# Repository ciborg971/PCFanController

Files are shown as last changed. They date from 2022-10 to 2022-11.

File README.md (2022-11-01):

# PCFanController

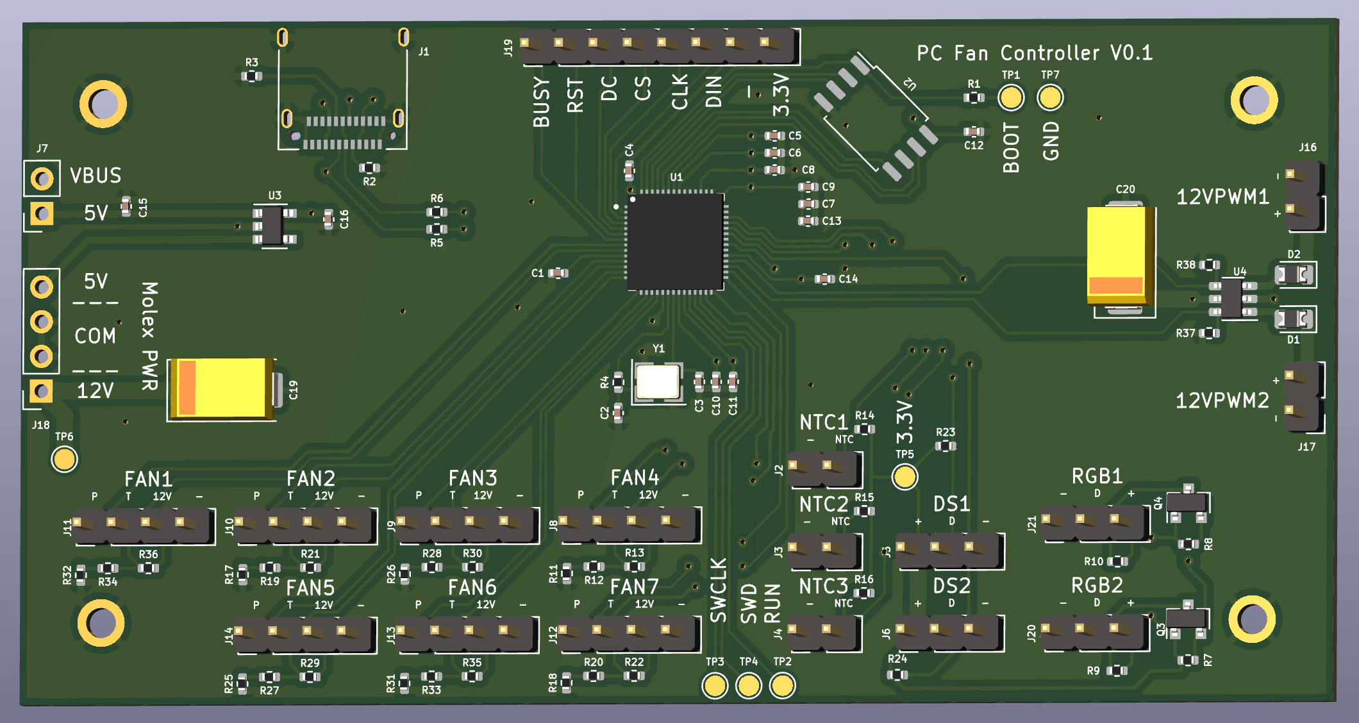
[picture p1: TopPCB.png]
PCB top view


A completly ~~overkill~~ sound and smart fan controller able to :
- use RP2040
- have USB-C
- 3x NTC 10K sensor (temperature sensor)
- 2x separated buses for DS18B20 (more temperature sensor)
- 2x separated WS2812 buses (RGB led)
- E-Ink display support
- 7x PWM fan support with tachymeter reading
- 2x 12 volt PWM output (Up to 20A per port)
- 2.5 inch hdd dimension (100 x 50 mm)
- M2 hole (between hole 85.25 x 38 mm)

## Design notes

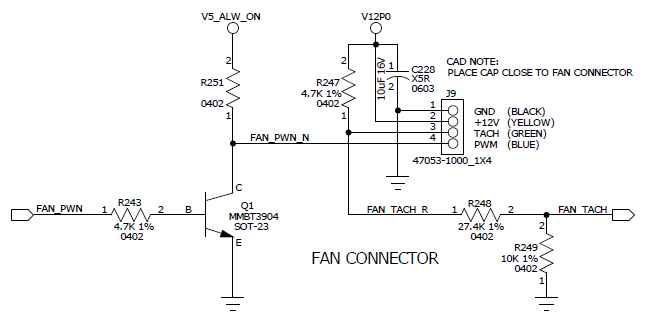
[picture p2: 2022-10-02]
doc/BKSFF.png

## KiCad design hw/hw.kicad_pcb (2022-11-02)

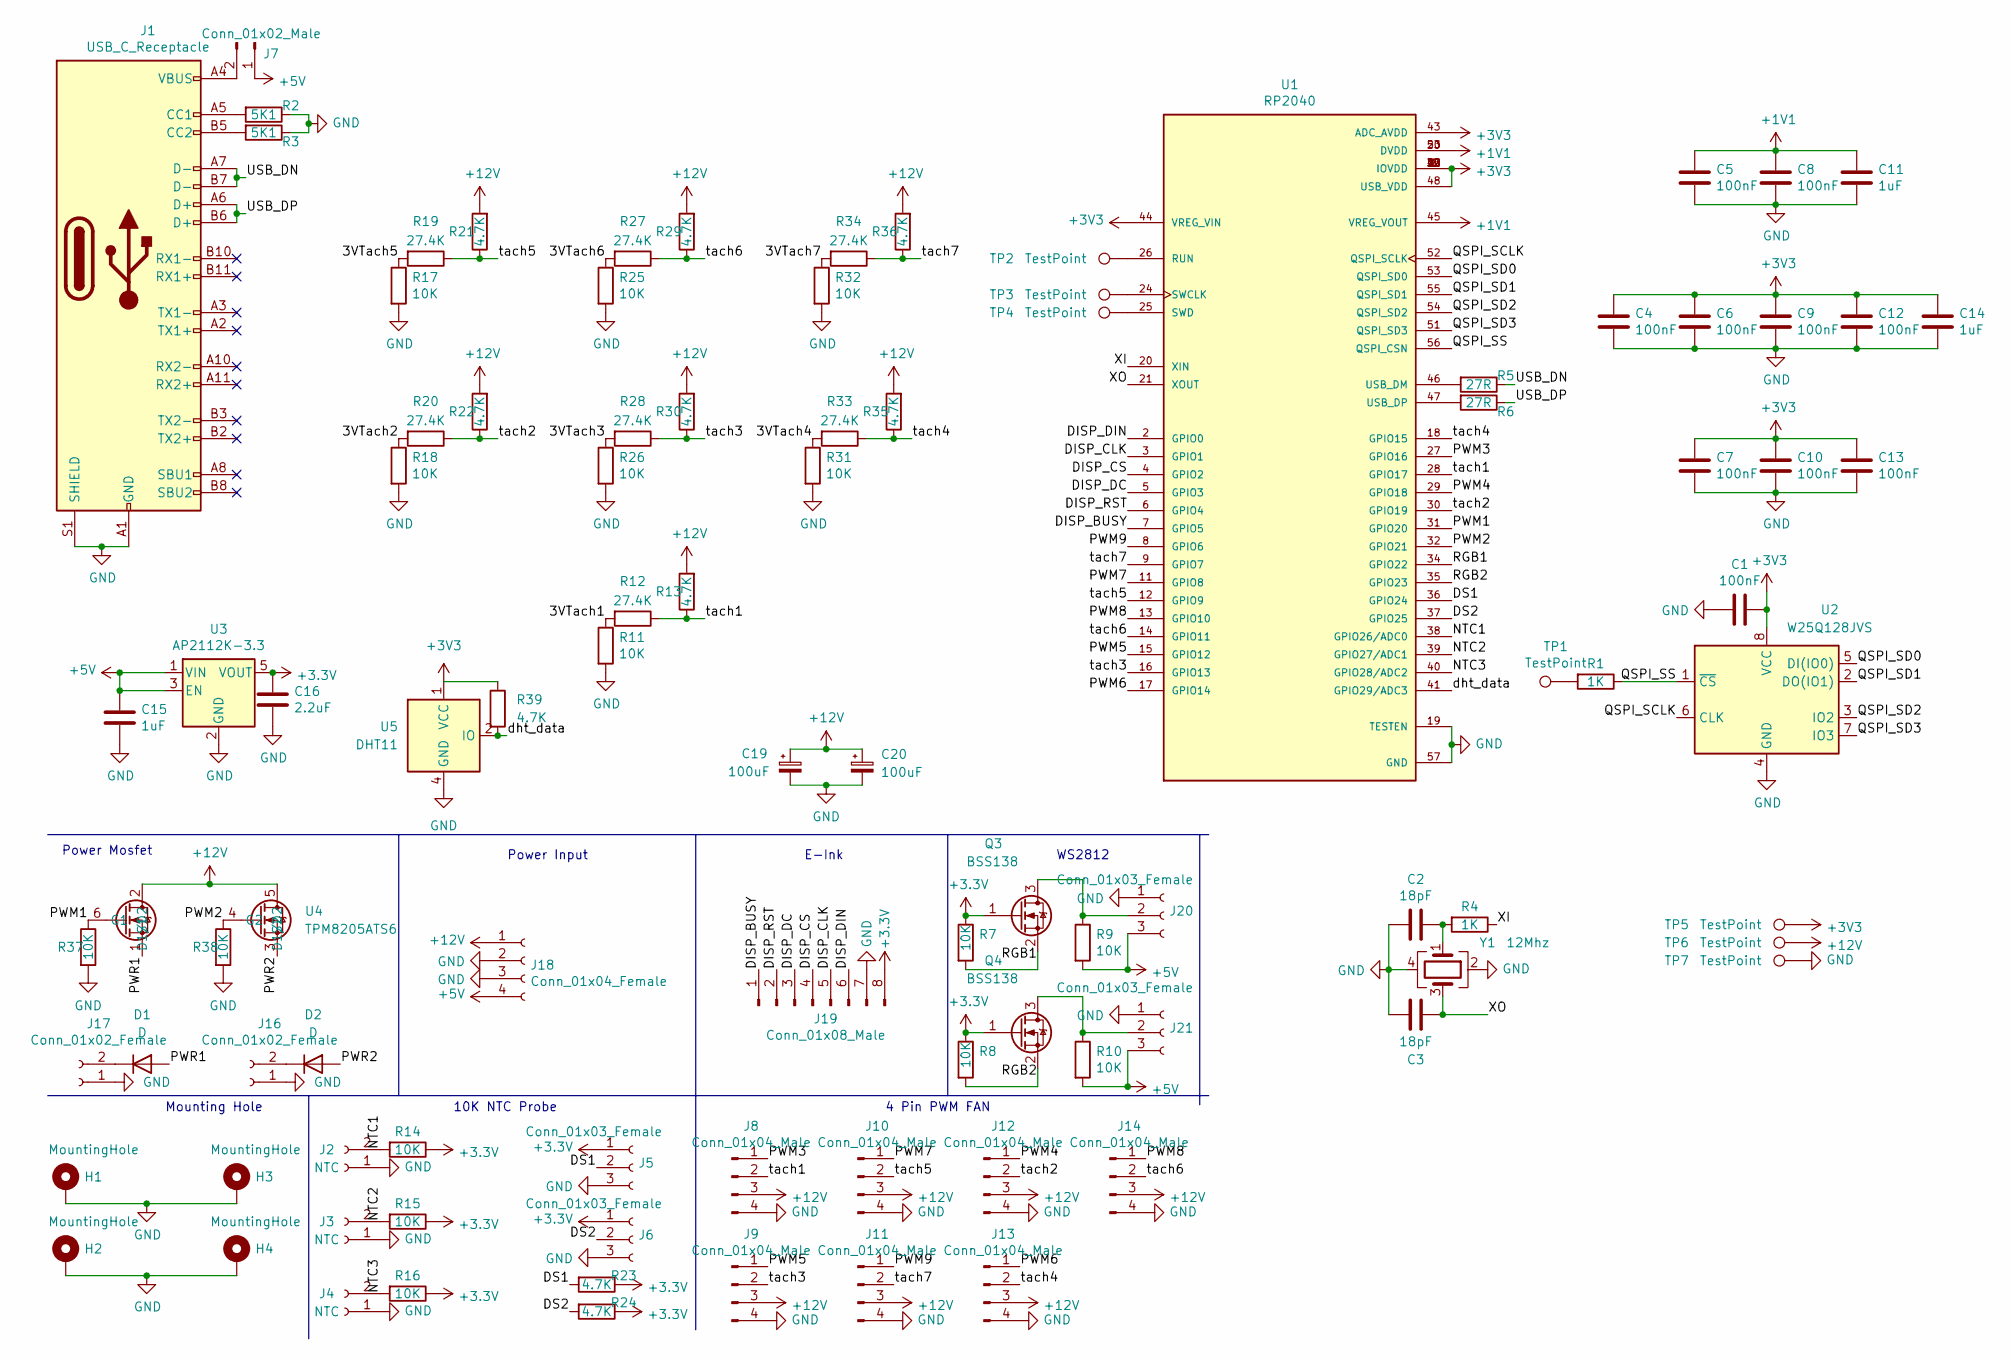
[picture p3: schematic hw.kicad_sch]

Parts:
C1, C4, C5, C6, C7, C8, C9, C10, C12, C13: 100nF; C_0402_1005Metric
C2, C3: 18pF; C_0402_1005Metric
C11, C14, C15: 1uF; C_0402_1005Metric
C16: 2.2uF; C_0402_1005Metric
C19, C20: 100uF; CP_EIA-7343-43_Kemet-X; LCSC C7230
D1, D2: D; D_0805_2012Metric
H1, H2, H3, H4: MountingHole; MountingHole_2.2mm_M2_ISO7380_Pad
J1: USB_C_Receptacle; USB_C_Receptacle_Amphenol_12401610E4-2A
J2, J3, J4: NTC; PinHeader_1x02_P2.54mm_Vertical
J5, J6, J20, J21: Conn_01x03_Female; PinHeader_1x03_P2.54mm_Vertical
J7: Conn_01x02_Male; PinSocket_1x02_P2.54mm_Vertical
J8, J9, J10, J11, J12, J13, J14: Conn_01x04_Male; PinHeader_1x04_P2.54mm_Vertical; LCSC C240840
J16, J17: Conn_01x02_Female; PinHeader_1x02_P2.54mm_Vertical
J18: Conn_01x04_Female; PinSocket_1x04_P2.54mm_Vertical
J19: Conn_01x08_Male; PinHeader_1x08_P2.54mm_Vertical
Q3, Q4: BSS138; SOT-23
R1, R4: 1K; R_0402_1005Metric
R2, R3: 5K1; R_0402_1005Metric
R5, R6: 27R; R_0402_1005Metric
R7, R8, R9, R10, R11, R14, R15, R16, R17, R18, R25, R26, R31, R32, R37, R38: 10K; R_0402_1005Metric
R12, R19, R20, R27, R28, R33, R34: 27.4K; R_0402_1005Metric
R13, R21, R22, R23, R24, R29, R30, R35, R36, R39: 4.7K; R_0402_1005Metric
TP1, TP2, TP3, TP4, TP5, TP6, TP7: TestPoint; TestPoint_Pad_D1.5mm
U1: RP2040; QFN40P700X700X90-57N; PARTREV 1.6.1; LCSC C2040
U2: W25Q128JVS; SOIC-8_5.23x5.23mm_P1.27mm; LCSC C82317
U3: AP2112K-3.3; SOT-23-5
U4: TPM8205ATS6; TSOT-23-6
U5: DHT11; Aosong_DHT11_5.5x12.0_P2.54mm
Y1: 12Mhz; Crystal_SMD_3225-4Pin_3.2x2.5mm; LCSC C124304

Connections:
+1V1: C5.1, C8.1, C11.1, U1.23 (DVDD), U1.45 (VREG_VOUT), U1.50 (DVDD)
+5V: C15.1, J7.1, J18.4, J20.3, J21.3, R9.2, R10.2, U3.1 (VIN), U3.3 (EN)
+12V: C19.1, C20.1, J8.3, J9.3, J10.3, J11.3, J12.3, J13.3, J14.3, J18.1, R13.2, R21.2, R22.2, R29.2, R30.2, R35.2, R36.2, TP6.1, U4.2 (D1/D2), U4.5 (D1/D2)
/3VTach1: R11.1, R12.2
/3VTach2: R18.1, R20.2
/3VTach3: R26.1, R28.2
/3VTach4: R31.1, R33.2
/3VTach5: R17.1, R19.2
/3VTach6: R25.1, R27.2
/3VTach7: R32.1, R34.2
/DISP_BUSY: J19.1, U1.7 (GPIO5)
/DISP_CLK: J19.5, U1.3 (GPIO1)
/DISP_CS: J19.4, U1.4 (GPIO2)
/DISP_DC: J19.3, U1.5 (GPIO3)
/DISP_DIN: J19.6, U1.2 (GPIO0)
/DISP_RST: J19.2, U1.6 (GPIO4)
/DS1: J5.2, R23.2, U1.36 (GPIO24)
/DS2: J6.2, R24.2, U1.37 (GPIO25)
/NTC1: J2.2, R14.2, U1.38 (GPIO26/ADC0)
/NTC2: J3.2, R15.2, U1.39 (GPIO27/ADC1)
/NTC3: J4.2, R16.2, U1.40 (GPIO28/ADC2)
/PWM1: R37.1, U1.31 (GPIO20), U4.6 (G1)
/PWM2: R38.1, U1.32 (GPIO21), U4.4 (G2)
/PWM3: J8.1, U1.27 (GPIO16)
/PWM4: J12.1, U1.29 (GPIO18)
/PWM5: J9.1, U1.15 (GPIO12)
/PWM6: J13.1, U1.17 (GPIO14)
/PWM7: J10.1, U1.11 (GPIO8)
/PWM8: J14.1, U1.13 (GPIO10)
/PWM9: J11.1, U1.8 (GPIO6)
/PWR1: D1.2 (A), U4.1 (S1)
/PWR2: D2.2 (A), U4.3 (S2)
/QSPI_SCLK: U1.52 (QSPI_SCLK), U2.6 (CLK)
/QSPI_SD0: U1.53 (QSPI_SD0), U2.5 (DI(IO0))
/QSPI_SD1: U1.55 (QSPI_SD1), U2.2 (DO(IO1))
/QSPI_SD2: U1.54 (QSPI_SD2), U2.3 (IO2)
/QSPI_SD3: U1.51 (QSPI_SD3), U2.7 (IO3)
/QSPI_SS: R1.1, U1.56 (QSPI_CSN), U2.1 (~CS)
/RGB1: Q3.2 (S), R7.2, U1.34 (GPIO22)
/RGB2: Q4.2 (S), R8.2, U1.35 (GPIO23)
/USB_DN: J1.A7 (D-), J1.B7 (D-), R5.1
/USB_DP: J1.A6 (D+), J1.B6 (D+), R6.1
/XI: R4.1, U1.20 (XIN)
/XO: C3.1, U1.21 (XOUT), Y1.3
/dht_data: R39.2, U1.41 (GPIO29/ADC3), U5.2 (IO)
/tach1: J8.2, R12.1, R13.1, U1.28 (GPIO17)
/tach2: J12.2, R20.1, R22.1, U1.30 (GPIO19)
/tach3: J9.2, R28.1, R30.1, U1.16 (GPIO13)
/tach4: J13.2, R33.1, R35.1, U1.18 (GPIO15)
/tach5: J10.2, R19.1, R21.1, U1.12 (GPIO9)
/tach6: J14.2, R27.1, R29.1, U1.14 (GPIO11)
/tach7: J11.2, R34.1, R36.1, U1.9 (GPIO7)
GND: C1.2, C2.2, C3.2, C4.2, C5.2, C6.2, C7.2, C8.2, C9.2, C10.2, C11.2, C12.2, C13.2, C14.2, C15.2, C16.2, C19.2, C20.2, H1.1, H2.1, H3.1, H4.1, J1.A1 (GND), J1.A12 (GND), J1.B1 (GND), J1.B12 (GND), J1.S1 (SHIELD), J2.1, J3.1, J4.1, J5.3, J6.3, J8.4, J9.4, J10.4, J11.4, J12.4, J13.4, J14.4, J16.1, J17.1, J18.2, J18.3, J19.7, J20.1, J21.1, R2.1, R3.1, R11.2, R17.2, R18.2, R25.2, R26.2, R31.2, R32.2, R37.2, R38.2, TP7.1, U1.19 (TESTEN), U1.57 (GND), U2.4 (GND), U3.2 (GND), U5.4 (GND), Y1.2, Y1.4
unnamed: C2.1, R4.2, Y1.1
unnamed: D1.1 (K), J17.2
unnamed: D2.1 (K), J16.2
unnamed: J1.A4 (VBUS), J1.A9 (VBUS), J1.B4 (VBUS), J1.B9 (VBUS), J7.2
unnamed: J1.A5 (CC1), R2.2
unnamed: J1.B5 (CC2), R3.2
unnamed: J20.2, Q3.3 (D), R9.1
unnamed: J21.2, Q4.3 (D), R10.1
unnamed: R1.2, TP1.1
unnamed: R5.2, U1.46 (USB_DM)
unnamed: R6.2, U1.47 (USB_DP)
unnamed: TP2.1, U1.26 (RUN)
unnamed: TP3.1, U1.24 (SWCLK)
unnamed: TP4.1, U1.25 (SWD)

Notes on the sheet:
Mounting Hole
Power Mosfet
10K NTC Probe
WS2812
Power Input
4 Pin PWM FAN
E-Ink

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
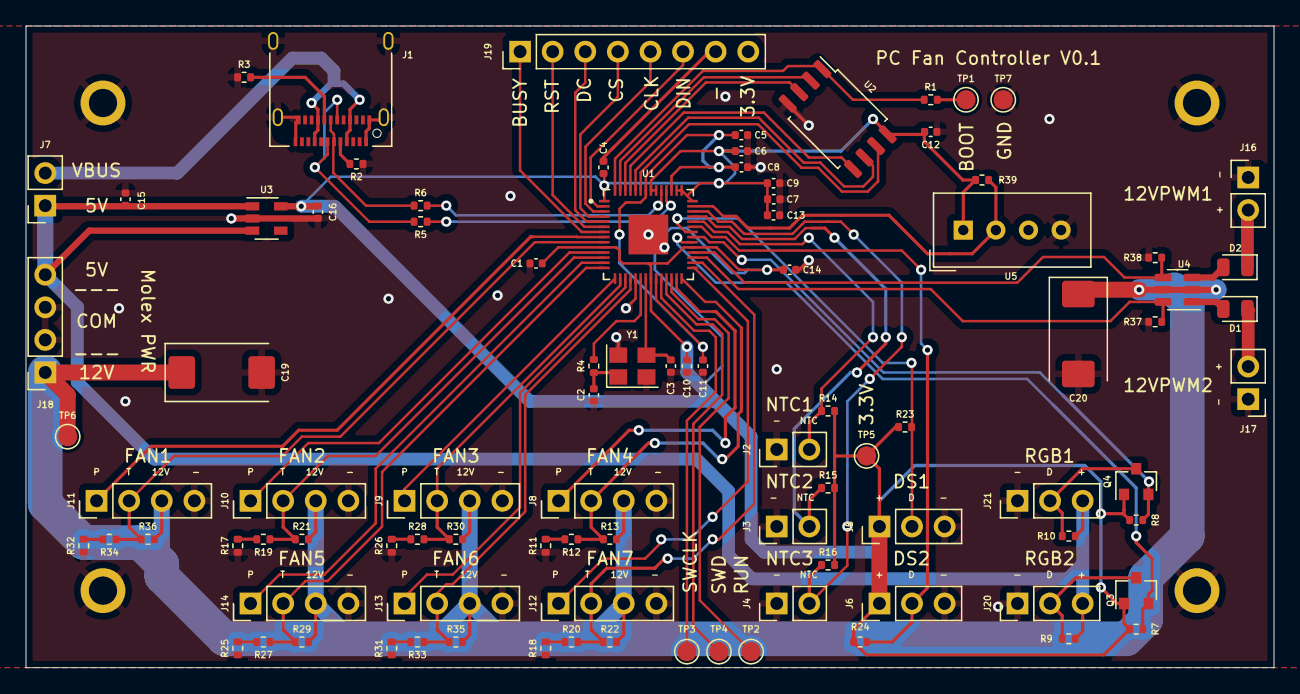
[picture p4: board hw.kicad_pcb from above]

Board: 2 copper layers, 97.2 x 50.0 mm, 98 parts (0 on the bottom side), 68 nets.

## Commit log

2022-09-30 schematic + placement of most component
    [hw.kicad_pcb, hw.sch]
2022-10-02 doc 4 pin fan schematic
2022-10-12 rooting progress + update readme + change power transistor
    [hw.kicad_pcb, hw.kicad_sch]
2022-11-01 add label, fix 12 v track width, connect everything
    [hw.kicad_pcb, hw.kicad_sch]
2022-11-01 reduce size of the board and update readme
    [hw.kicad_pcb]
2022-11-02 add dht11/22 support
    hwmon have humidity support and... i have some dht laying aroung ...
    [hw.kicad_pcb, hw.kicad_sch]
